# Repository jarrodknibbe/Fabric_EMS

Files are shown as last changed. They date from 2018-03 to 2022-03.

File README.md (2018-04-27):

# Temera - EMS eTextile Shield for Teensy

TL;DR - A custom board and code for integrating electronics (especially EMS) into fabric garments.

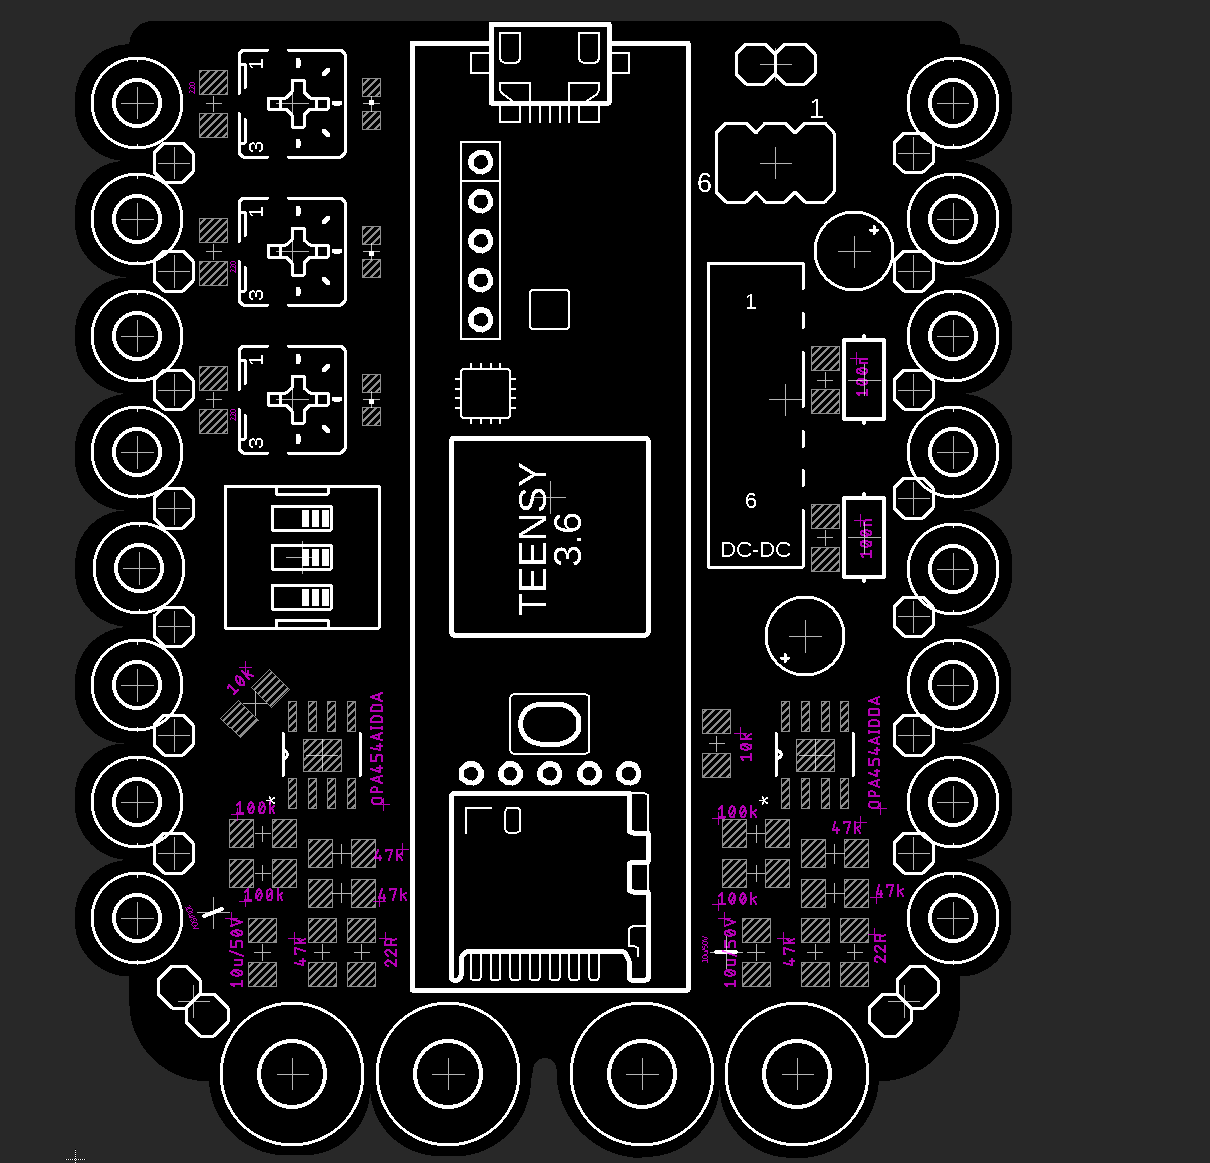
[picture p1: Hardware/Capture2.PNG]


Temera is a soft, finnles, Sleeper Ray, with paired electric organs. Temera is also a platform for creating soft circuits with paired EMS stimulation outputs.

Specifically, Temera is a prototype two-channel EMS shield, designed to be easily incorporated into fabrics.
16 GPIO that can be set to Analog Input as well as 2 Channels of EMS are broken out. In addition to pins, we added holes, so that each channel can easily be connected to using conductive thread. 

This is an early prototype that is still under active development. More details to follow.

Code:

The driver code is available in this repository as well. The stable implementation provides all of the basic code to get you started. There is also a 'dev_code' version of the code available, where we continue to play with further developments. (We recommend using the stable implementation, at least until you are comfortable with its operation).

Work from the Run_EMS.ino file. This handles the board and the EMS signal generation. The signal generation works through a series of timers handled by the Teensy. There are individual timers per channel frequency and pulse width. Per channel, a frequency timer ticks along at the desired frequency of stimulation. This frequency timer then handles triggering the pulse width timer to run, so that each pulse of EMS is the correct shape / length. 

DEV_Code changes:
+ Basic sensor integration outline - stim if some sensor value between x and y
+ Change potentiometer to work constantly when in manual update mode 

(Worth noting, Teensys are more stable on Windows than on a Mac).

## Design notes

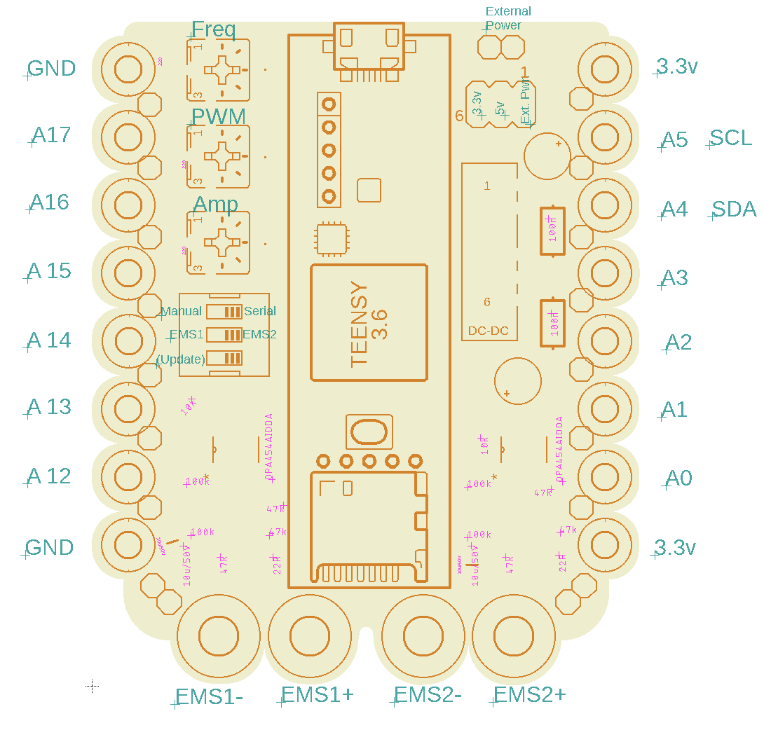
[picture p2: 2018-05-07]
labels.PNG

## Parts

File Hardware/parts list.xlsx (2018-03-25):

Part | Old PartName | Value | Package | Comment | Qnt. | URL
C1 |  | 100n | 1206 |  | 2x | https://www.digikey.dk/product-detail/en/yageo/CC1206KRX7R9BB104/311-1179-1-ND/303089
C2 |  | 100n | 1206 |  | 0x
C3 |  | E2,5-5 | resistor | empty (backup for 100n) | 0x
C4 |  | E2,5-5 | resistor | empty (backup for 100n) | 0x
DC-DC |  |  |  | Backup |  | https://www.digikey.dk/products/en?keywords=XP%20Power%20IH0524SH
DC-DC |  | NMA | dc-dc-converter |  | 1x | https://www.digikey.dk/products/en?keywords=PEM2-S5-D24-S
E1_BACKUP |  | 10u/50V | CAP-PTH-5MM | empty (backup 10u / 50v) | 0x
E1_CAP |  | 10u/50V | 1206 |  | 2x | https://www.digikey.dk/product-detail/en/samsung-electro-mechanics/CL31A106KBHNNNE/1276-2876-2-ND/3888534
E1_OPA |  | OPA454AIDDA | SOIC127P600X170-9N | R90 | 2x | https://www.digikey.dk/product-detail/en/texas-instruments/OPA454AIDDA/296-22997-5-ND/1770310
E1_OUT |  | 1X02 | pinhead | empty | 0x
E1_R_DAC |  | 47k | 1206 |  | 6x | https://www.digikey.dk/product-detail/en/yageo/RC1206FR-0747KL/311-47.0KFRCT-ND/731878
E1_R1 |  | 100k | 1206 |  | 4x | https://www.digikey.dk/product-detail/en/yageo/RC1206FR-07100KL/311-100KFRCT-ND/731439
E1_R2 |  | 100k | 1206 |  | 0x
E1_R3 |  | 47k | 1206 |  | 0x
E1_R4 |  | 47k | 1206 |  | 0x
E1_R5 |  | 22R Ohm | 1206 | what unit is this? I'll get both | 2x | https://www.digikey.dk/product-detail/en/yageo/RC1206FR-0722RL/311-22.0FRCT-ND/731634
E1_R5 | Backup | 22R kOhm | 1206 | Backup | 2x | https://www.digikey.dk/product-detail/en/yageo/RC1206FR-0722KL/311-22.0KFRCT-ND/731635
E2_BACKUP |  | 10u/50V | CAP-PTH-5MM | empty (backup 10u / 50v) | 0x
E2_CAP |  | 10u/50V | 1206 |  | 0x
E2_OPA | U2 | OPA454AIDDA | SOIC127P600X170-9N | R90 | 0x
E2_OUT |  | 1X02 | pinhead |  | 0x
E2_R_DAC |  | 47k | 1206 |  | 0x
E2_R1 |  | 100k | 1206 |  | 0x
E2_R2 |  | 100k | 1206 |  | 0x
E2_R3 |  | 47k | 1206 |  | 0x
E2_R4 |  | 47k | 1206 |  | 0x
E2_R5 |  | 22R | 1206 |  | 0x
EXT_PWR |  | 1X02 | pinhead |  | 1x
LED1 |  | CHIPLED_0805 | led |  | 3x | https://www.digikey.dk/product-detail/en/osram-opto-semiconductors-inc/LS-R976-NR-1/475-1278-1-ND/1642798
LED2 |  | CHIPLED_0805 | led |  | 0x
LED3 |  | CHIPLED_0805 | led |  | 0x
LEDR1 |  | 220 | 1206 |  | 3x | https://www.digikey.dk/product-detail/en/yageo/RC1206FR-0768RL/311-68.0FRCT-ND/732007
LEDR2 |  | 220 | 1206 |  | 0x
LEDR3 |  | 220 | 1206 |  | 0x
P1 |  | B25P | pot |  | 3x | https://www.digikey.dk/product-detail/en/bourns-inc/3362P-1-103TLF/3362P-103TLF-ND/1232540
P2 |  | B25P | pot |  | 0x
P3 |  | B25P | pot |  | 0x
R20 |  | 10k | 1206 |  | 2x | https://www.digikey.dk/product-detail/en/yageo/RC1206FR-0710KL/311-10.0KFRCT-ND/731430
R21 |  | 10k | 1206 |  | 0x
R7 |  | AXIAL-0.3-KIT | SparkFun-Resistors |  | 0
R8 |  | AXIAL-0.3-KIT | SparkFun-Resistors |  | 0
SRC_SELECT |  | MA03-2 | con-lstb | 3*2 pinhead | 1x | https://www.digikey.dk/product-detail/en/harwin-inc/M20-9980346/952-2121-ND/3728085
SW1 |  | EDG-03 | special | Switch IC | 1x | https://www.digikey.dk/product-detail/en/grayhill-inc/76SB03T/GH7168-ND/726226
TEENSY | U$1 | TEENSY_3.5/3.6_BASIC | TEENSY_3.5/3.6_BASIC | Get headers too | 2x | https://www.digikey.dk/product-detail/en/sullins-connector-solutions/NRPN241PAEN-RC/S5800-24-ND/804937
Jumper |  |  |  |  | 1x | https://www.digikey.dk/product-detail/en/te-connectivity-amp-connectors/2-881545-2/2-881545-2-ND/2055953
Jumper b |  |  |  |  | 1x | https://www.digikey.dk/product-detail/en/sullins-connector-solutions/SPN02SYBN-RC/S3404-ND/927356
female pins |  |  |  |  | 2x | https://www.digikey.dk/product-detail/en/sullins-connector-solutions/PPTC241LFBN-RC/S7022-ND/810162

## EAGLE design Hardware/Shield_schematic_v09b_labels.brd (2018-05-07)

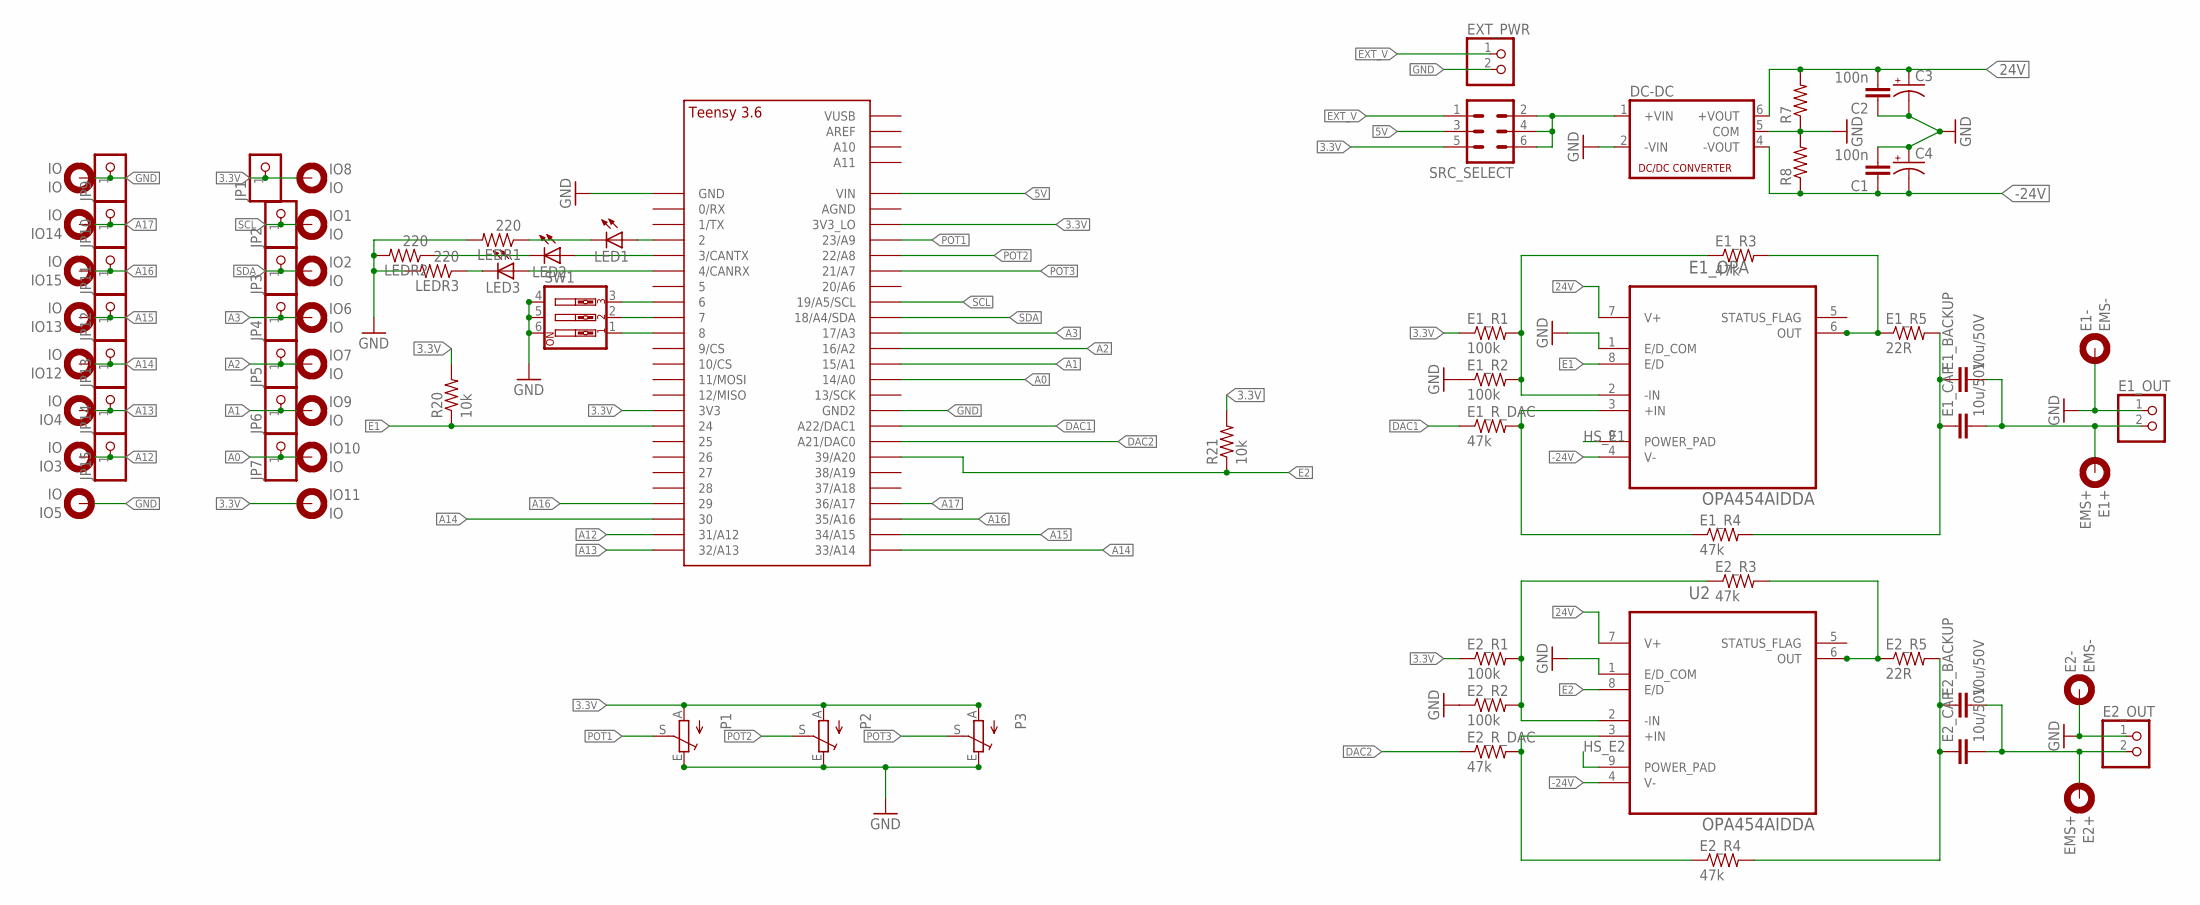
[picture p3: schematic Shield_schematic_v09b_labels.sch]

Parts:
C1, C2: 100n; 1206
C3, C4: CPOL-USE2.5-5; E2,5-5
DC-DC: NMA
E1+, E2+: EMS+; 4,1-PAD
E1-, E2-: EMS-; 4,1-PAD
E1_BACKUP, E2_BACKUP: 10u/50V; CAP-PTH-5MM
E1_CAP, E2_CAP: 10u/50V; 1206
E1_OPA: OPA454AIDDA; SOIC127P600X170-9N
E1_OUT, E2_OUT: PINHD-1X2; 1X02
E1_R1, E1_R2, E2_R1, E2_R2: 100k; 1206
E1_R3, E1_R4, E1_R_DAC, E2_R3, E2_R4, E2_R_DAC: 47k; 1206
E1_R5, E2_R5: 22R; 1206
EXT_PWR: PINHD-1X2; 1X02
IO, IO1, IO2, IO3, IO4, IO5, IO6, IO7, IO8, IO9, IO10, IO11, IO12, IO13, IO14, IO15: IO; 2,8-PAD
JP1, JP2, JP3, JP4, JP5, JP6, JP7, JP9, JP10, JP11, JP12, JP13, JP14, JP15: PINHD-1X1; 1X01
LED1, LED2, LED3: LEDCHIPLED_0805; CHIPLED_0805
LEDR1, LEDR2, LEDR3: 220; 1206
P1, P2, P3: TRIM_EU-B25P; B25P
R7, R8: RESISTORKIT; AXIAL-0.3-KIT
R20, R21: 10k; 1206
SRC_SELECT: MA03-2
SW1: SW_DIP-3; EDG-03
U2: OPA454AIDDA; SOIC127P600X170-9N
U$1: TEENSY_3.5/3.6_BASIC

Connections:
3.3V: E1_R1.1, E2_R1.1, IO8.B2,8, IO11.B2,8, JP1.1, P1.A, P2.A, P3.A, R20.2, R21.2, SRC_SELECT.5, U$1.3V3, U$1.3V3_LO
5V: SRC_SELECT.3, U$1.VIN
24V: C2.2, C3.+, DC-DC.6 (+VOUT), E1_OPA.7 (V+), R7.P$2 (2), U2.7 (V+)
-24V: C1.1, C4.-, DC-DC.4 (-VOUT), E1_OPA.4 (V-), R8.P$1 (1), U2.4 (V-)
A0: IO10.B2,8, JP7.1, U$1.14/A0
A1: IO9.B2,8, JP6.1, U$1.15/A1
A2: IO7.B2,8, JP5.1, U$1.16/A2
A3: IO6.B2,8, JP4.1, U$1.17/A3
A12: IO3.B2,8, JP15.1, U$1.31/A12
A13: IO4.B2,8, JP14.1, U$1.32/A13
A14: IO12.B2,8, JP13.1, U$1.30, U$1.33/A14
A15: IO13.B2,8, JP12.1, U$1.34/A15
A16: IO15.B2,8, JP11.1, U$1.29, U$1.35/A16
A17: IO14.B2,8, JP10.1, U$1.36/A17
DAC1: E1_R_DAC.1, U$1.A22/DAC1
DAC2: E2_R_DAC.1, U$1.21/DAC0 (A21/DAC0)
E1: E1_OPA.8 (E/D), R20.1, U$1.24
E1+: E1+.B4,1, E1_BACKUP.2, E1_CAP.2, E1_OUT.2
E2: R21.1, U2.8 (E/D), U$1.39/A20
E2+: E2+.B4,1, E2_BACKUP.2, E2_CAP.2, E2_OUT.2
EXT_V: EXT_PWR.1, SRC_SELECT.1
GND: C1.2, C2.1, C3.-, C4.+, DC-DC.2 (-VIN), DC-DC.5 (COM), E1-.B4,1, E1_OPA.1 (E/D_COM), E1_OUT.1, E1_R2.1, E2-.B4,1, E2_OUT.1, E2_R2.1, EXT_PWR.2, IO.B2,8, IO5.B2,8, JP9.1, LEDR1.2, LEDR2.2, LEDR3.2, P1.E, P2.E, P3.E, R7.P$1 (1), R8.P$2 (2), SW1.4, SW1.5, SW1.6, U2.1 (E/D_COM), U$1.GND, U$1.GND2
HS_E1: E1_OPA.9 (POWER_PAD)
HS_E2: U2.9 (POWER_PAD)
unnamed: SW1.1, U$1.8
unnamed: E1_OPA.3 (+IN), E1_R4.1, E1_R_DAC.2
unnamed: E1_BACKUP.1, E1_CAP.1, E1_R4.2, E1_R5.2
unnamed: LED1.A, U$1.2
unnamed: E1_OPA.6 (OUT), E1_R3.2, E1_R5.1
unnamed: SW1.2, U$1.7
unnamed: E1_OPA.2 (-IN), E1_R1.2, E1_R2.2, E1_R3.1
unnamed: SW1.3, U$1.6
unnamed: E2_R4.1, E2_R_DAC.2, U2.3 (+IN)
unnamed: E2_BACKUP.1, E2_CAP.1, E2_R4.2, E2_R5.2
unnamed: LED2.A, U$1.3/CANTX
unnamed: E2_R3.2, E2_R5.1, U2.6 (OUT)
unnamed: LED3.A, U$1.4/CANRX
unnamed: E2_R1.2, E2_R2.2, E2_R3.1, U2.2 (-IN)
unnamed: LED1.C, LEDR1.1
unnamed: DC-DC.1 (+VIN), SRC_SELECT.2, SRC_SELECT.4, SRC_SELECT.6
unnamed: LED2.C, LEDR2.1
unnamed: LED3.C, LEDR3.1
POT1: P1.S, U$1.23/A9
POT2: P2.S, U$1.22/A8
POT3: P3.S, U$1.21/A7
SCL: IO1.B2,8, JP2.1, U$1.19/A5/SCL
SDA: IO2.B2,8, JP3.1, U$1.18/A4/SDA

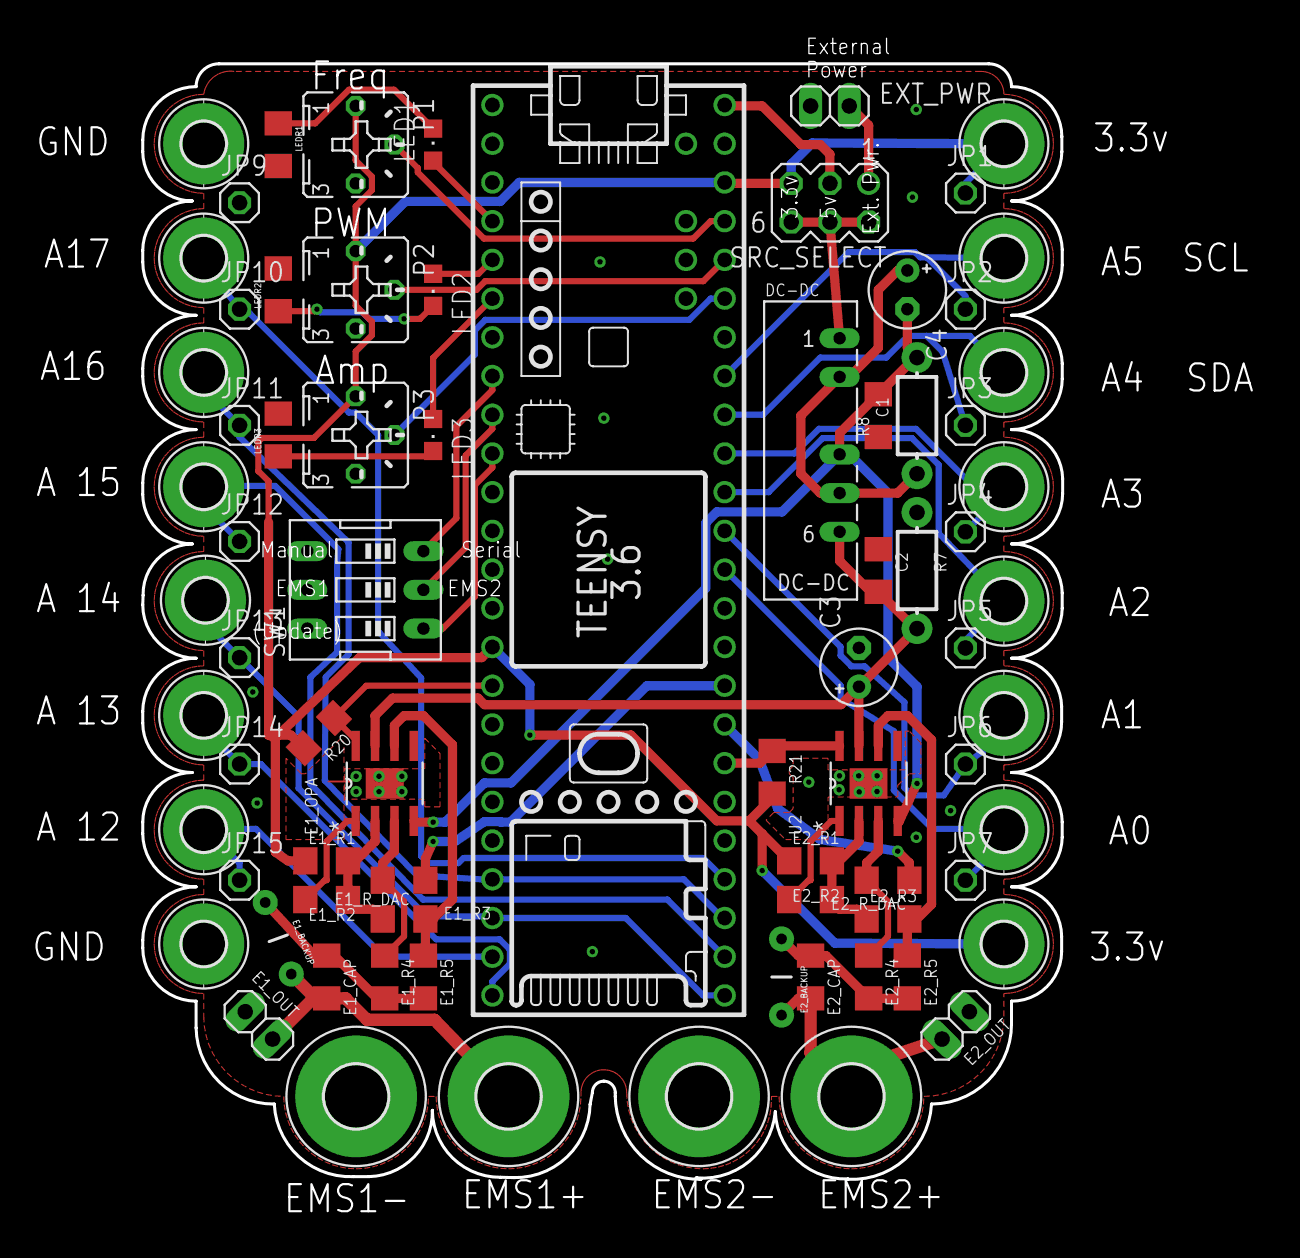
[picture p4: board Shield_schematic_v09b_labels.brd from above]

Board: 2 copper layers, 60.4 x 73.2 mm, 76 parts (0 on the bottom side), 45 nets.

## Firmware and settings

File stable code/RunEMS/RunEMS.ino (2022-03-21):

#include "EMSboard.h"

//Create the board object
//The board provides interfacing to all functionality
//and includes the two EMS channels
EMSboard board;

//Matt
int pinOut = A17; //Output pin of LED flash
int pinIn = A16; //Input pin checking if button is pressed
int timeStart; //Init of start of reaction time variable
int timeEnd; //Init of end of reaction time variable
int reactionTime = 0; //Init reaction time as 0

//Intervaltimers are responsible for scheduling all stimulation
//They have to sit here unfortunately due to programming challenges
IntervalTimer freqTimer1, freqTimer2, pwmTimer1, pwmTimer2;

//In total the Teensy offers 4 interval timers, we use them all.
//There are two frequency timers, that trigger the below two functions
//for example, the below functions might run at 80Hz and 60Hz, respectively,
//to trigger stimulation.
void frequency_action_channel1()
{
  pwmTimer1.priority(15);
  pwmTimer1.begin(pwm_action_channel1, board.getChannelpwm(0));
}

void frequency_action_channel2()
{
  pwmTimer2.priority(17);
  pwmTimer2.begin(pwm_action_channel2, board.getChannelpwm(1));
}

//The frequency functions, when they are triggered, then start pulse width clocks
//These clocks control the shape of the stimulation. At the moment,
//they push the signal high, then low, then off. Creating a biphasic square wave. 
//You could experiment with signal shape, but changing the response of the
//pulse step function.
void pwm_action_channel1()
{
  int result = board.pulse_step(0);

  if (result == 1) pwmTimer1.end();
}

void pwm_action_channel2()
{
  int result = board.pulse_step(1);

  if (result == 1) pwmTimer2.end();
}

//This function sets up the frequency triggers to run at the desired frequency
//This function also handles any update to frequency. 
void create_timers()
{
  Serial.println("Create timers");
  freqTimer1.end();
  freqTimer2.end();
  freqTimer1.priority(10);
  freqTimer2.priority(11);

  freqTimer1.begin(frequency_action_channel1, (1. / board.getChannelfreq(0)) * 1000000.);
  freqTimer2.begin(frequency_action_channel2, (1. / board.getChannelfreq(1)) * 1000000.);
}

//Set up the board, and the timers, and start some very light stimulation.
//(You probably couldn't feel it.)
void setup() {
  //Serial.begin(9600);
  board.init();
  //create_timers();

  board.stimulate(0,80,120,3);
  board.stimulate(1,60,140,3);

  pinMode(pinOut, OUTPUT); //Set LED pin as output
  pinMode(pinIn, INPUT); //Set button pin as input
}

//This function runs all the time.
//At the moment, it looks for updates to the blue potentiometers on the board
//and the red switches. If it finds switch updates, it calls create_timers
//to update the timers. 
void loop() {
 if (board.step()) create_timers(); 
 // Check whether any control input has been given
 // Use this to programmatically update the stimulation parameters
 // Format of updates: 'nc, a, f, p' (e.g. 1c 5 100 50 updates channel 1 to amp 5, freq 100 and pwm 50)
 if (Serial.available()){
    int channelVal = Serial.parseInt();
    int labelChan = Serial.read();
    int commanda = Serial.parseInt();
    int commandf = Serial.parseInt();
    int commandp = Serial.parseInt();

    if (labelChan == 'c') board.setParameters(channelVal, commandf, commandp, commanda);

    if (labelChan == 't'){
        board.setParameters(channelVal, commandf, commandp, commanda);
        create_timers();
    }
        
        
        
        // for (int i = 0; i <= 30; i++) {
        //  delay(4000); // Wait 3 seconds before flashing the LED (this should be changed to a random time between 1-5 seconds)
        digitalWrite(pinOut,HIGH); //After x time turn on LED
        timeStart = millis(); //Start the timer as soon as LED turns on

        delay(50); //EMS delay (theorhetically should be 205ms)
        board.stimulate(channelVal,-1,commandp,commanda);
        delay(10); // extend this pulse time.
        board.stopStimulation(channelVal);
  
        while (digitalRead(pinIn) == LOW) {
    
        }
  
        timeEnd = millis(); //'stop' the timer as soon as button is pressed
        digitalWrite(pinOut,LOW); //turn of LED
        reactionTime = timeEnd - timeStart; //record time difference to find reaction time

        Serial.print(reactionTime/1000.0, 3); //print reaction time to computer
        Serial.print(" s, This is reaction time in seconds");
        Serial.println(" ");
        timeStart = 0; 
        timeEnd = 0; //reset timer
        
       
    }
  
  delay(20);
}

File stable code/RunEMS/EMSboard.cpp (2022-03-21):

#include "Arduino.h"
#include "EMSboard.h"


void EMSboard::init()
{
  channels[0].init_channel(24, A22, 0);
  channels[1].init_channel(39, A21, 1);

  channels[0].setStimulationParameters(80,120,3);
  channels[1].setStimulationParameters(60,160,3);

  switchState = getSwitchState();

  for (int i = 0; i < 3; i++)
  {
    pinMode(LEDs[i], OUTPUT);
    pinMode(switches[i], INPUT_PULLUP);
    pinMode(pots[i], INPUT);
  }

  analogWriteResolution(9);
}

void EMSboard::stimulate(int _channel, int _freq, int _pwm, int _amp)
{
  //if (_freq != -1)
  //{
    channels[_channel].startStimulation(_freq, _pwm, _amp);
  //}
  
}

void EMSboard::stopStimulation(int _channel)
{
  channels[_channel].stopStimulation();
}

int EMSboard::getSwitchState()
{
  int state = 0;
  for (int i = 0; i < 3; i++)
  {
    if (digitalRead(switches[i]) == HIGH){
      state += (1 << i);
    }
  }
  return state;
}

void EMSboard::useManualEMSControl(bool _use)
{
  manualEMSControl = _use;
}

void EMSboard::setParameters(int channel, int _freq, int _pwm, int _amp)
{
  channels[channel].setStimulationParameters(_freq, _pwm, _amp);
}

bool EMSboard::step()
{
  useManualEMSControl(bitRead(getSwitchState(), 0));
  
  if (manualEMSControl)
  {
    setLEDBrightness(bitRead(getSwitchState(), 1), (int)analogRead(pots[2])/4);
    
    if (bitRead(getSwitchState(), 2) != bitRead(switchState,2))
    {
      switchLED(2);
      int _freq = (int)(analogRead(pots[0])/4);
      int _pwm = (int)(analogRead(pots[1])/4);
      int _amp = (int)(analogRead(pots[2])/4);
      Serial.print(_freq);
      Serial.print(" ");
      Serial.print(_pwm);
      Serial.print(" ");
      Serial.println(_amp);
      setParameters(bitRead(getSwitchState(), 1), _freq, _pwm, _amp);
      switchState = getSwitchState();
      return true;
    }
  }

  return false;
}

int EMSboard::pulse_step(int _chan)
{
  return channels[_chan].stimulation_step();
}

void EMSboard::switchLED(int _index)
{
  digitalWrite(LEDs[_index], !digitalRead(LEDs[_index]));
}

void EMSboard::setLEDBrightness(int _index, int value)
{
  analogWrite(LEDs[_index], value);
}

int EMSboard::getChannelpwm(int _chan)
{
  return channels[_chan].get_pwm();
}

int EMSboard::getChannelfreq(int _chan)
{
  return channels[_chan].get_freq();
}

int EMSboard::getChannelamp(int _chan)
{
  return channels[_chan].get_amp();
}

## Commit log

2018-03-25 eagle files + partlist
    [Shield_schematic_v09b.brd, Shield_schematic_v09b.sch, parts list.xlsx]
2018-05-07 mainly fixed UI related things
    changed the pot behavior so its more intuitive, made the debug information clearer.
    [EMSboard.cpp, EMSchannel.cpp, RunEMS.ino]
2018-05-07 making it less noisy
    I was getting too many channel updates, so I increased the threshold by turning >= to just > .
    This is a lazy fix. Should use some sort of filtering instead.
    [Shield_schematic_v09b_labels.brd, Shield_schematic_v09b_labels.sch]
2022-03-21 added new channel label
    added channel label that pulses EMS stimulation to give 30 individual finger actuations at a set freq,wd,pw,amp.
    Also updated EMSchannel to check if EMSstimulate = true

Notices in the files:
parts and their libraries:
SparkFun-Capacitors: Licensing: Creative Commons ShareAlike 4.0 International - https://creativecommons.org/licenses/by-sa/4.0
